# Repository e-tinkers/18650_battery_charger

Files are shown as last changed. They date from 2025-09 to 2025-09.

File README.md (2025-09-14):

## What this about
This repository contains the design files for my 18650 and single cell Li-Po charger which also consists of load-shring circuitry, and a buck/boost converter (3.3V/5.0V, 500mA output) with very low quiescent current (20uA).

18650 battery charger PCB with load sharing and buck/boost converter

## The motivation
All the 18650 battery chargers that can be found from AliExpress have serious design faults, and the 18650 battery is safer to be used with the protection circuit permanently attached to it. With the modification added to 18650, the commercial available battery holders for 18650 no longer fit. So I decided to design my own charger with custom 18650 battery holder to fit the modified battery, and add a low quiescent current buck/boost converter with 3.3V/5V output that I can used for my electronic projects.

add protection circuit permanently to 18650 battery

## The design goals
1. On-board 18650 battery holder able to fit standard 18650 and modified one;
2. USB Type C power input port;
3. Capable to charge either 18650 battery and Li-Po battery (via JST connector);
4. Battery Protection for standard 18650 battery;
5. Load-sharing circuitry so it can power the load while charging;
6. Boost/Buck converter capable to deliver 500mA power with either 3.3V or 5V output;
7. Low quiescent current for IoT application.

Read more in details about the design considerations from my [blog post](https://www.e-tinkers.com/2025/08/design-my-own-tp4056-li-ion-charger-and-iot-power-supply-subsystem/).

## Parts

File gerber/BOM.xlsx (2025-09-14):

Symbol | Value | Description | Qty | LCSC Part No | MOQ | Unit Price | Order Qty | BOM Cost | Order Amount
BT1 | 18650_holder | 18650_holder:18650_holder_PH | 1 | C5290176 | 1 | 0.4061 | 5 | 0.4061 | 2.0305
C4 | 10uF | Capacitor_SMD:C_0603_1608Metric | 1 |  |  | 0.0157 |  | 0.0157
> C1, C2 | 22uF | Capacitor_SMD:C_0603_1608Metric | 2 | C86295 | 50 | 0.0129 | 50 | 0.0258 | 0.0129
> C3, C5, C6 | 0.1uF | Capacitor_SMD:C_0603_1608Metric | 3 |  |  | 0.0022 |  | 0.0066
D1 | BAT60A | Diode_SMD:D_SOD-323 | 1 | C5355496 | 10 | 0.0345 | 20 | 0.0345 | 0.0345
D2 | PWR | LED_SMD:LED_0603_1608Metric | 1 |  |  | 0.015 |  | 0.015
D3 | CHRG | LED_SMD:LED_0603_1608Metric | 1 |  |  | 0.015 |  | 0.015
D4 | STDBY | LED_SMD:LED_0603_1608Metric | 1 |  |  | 0.0178 |  | 0.0178
J1 | Connector_USB_C | XUNPU_TYPEC-304-ACP16:XUNPU_TYPEC-304-ACP16 | 1 |  |  |  |  | 0.01202
J2 | Output | Connector_PinSocket_2.54mm:PinSocket_1x02_P2.54mm_Vertical | 1 |  |  |  |  | 0.0137
J3 | JST PH2 | JST_PH_S2B-PH-SM4-TB_1x02-1MP_P2.00mm_Horizontal | 1 | C7429689 | 10 | 0.0339 | 10 | 0.0288 | 0.339
JP1 | VLED | Jumper:SolderJumper-2_P1.3mm_Bridged_RoundedPad1.0x1.5mm | 1 |  |  |  |  | 0
L1 | 0.47uH | Inductor_SMD:L_Taiyo-Yuden_NR-50xx | 1 | C222905 | 1 | 0.0838 | 10 | 0.0838 | 0.838
Q1 | FDN340P | Package_TO_SOT_SMD:SOT-23_Handsoldering | 1 |  |  |  |  | 0.0463
Q2 | 8205A | 8205A:SOP65P640X120-8N | 1 | C7419210 | 10 | 0.0646 | 10 | 0.0646 | 0.646
R2 | 511k 1% | Resistor_SMD:R_0603_1608Metric | 1 | C861454 | 20 | 0.0366 | 20 | 0.0366 | 0.732
R1 | 309k 1% | Resistor_SMD:R_0603_1608Metric | 1 | C4151043 | 100 | 0.0012 | 100 | 0.0012 | 0.12
R3 | 91k 1% | Resistor_SMD:R_0603_1608Metric | 1 | C137671 | 100 | 0.0067 | 100 | 0.0067 | 0.67
R4 | 100k | Resistor_SMD:R_0603_1608Metric | 1 |  | 100 | 0.001 |  | 0.001
> R6, R7 | 5.1k | Resistor_SMD:R_0603_1608Metric | 2 |  |  | 0.0022 |  | 0.0044
R8 | 100 | Resistor_SMD:R_0603_1608Metric | 1 |  |  | 0.0011 |  | 0.0011
> R5, R9, R10, R12 | 2k | Resistor_SMD:R_0603_1608Metric | 4 | C125933 | 100 | 0.0021 | 100 | 0.0084 | 0.21
R11 | 1k | Resistor_SMD:R_0603_1608Metric | 1 |  |  |  |  | 0.0009
SW1 | PWR | switches:SW_SPDT_MK-12C02 | 1 | C963206 |  |  |  | 0.058
SW2 | SW_DIP_x01 | Button_Switch_SMD:SW_DIP_SPSTx01_Slide_Copal_CHS-01A_W5.08mm_P1.27mm_JPin | 1 | C18198097 | 1 | 0.5728 | 5 | 0.5728 | 2.864
SW3 | BATT | switches:SW_SPDT_MK-12C02 | 1 | C963206 | 10 | 0.058 | 10 | 0.058 | 0.58
U1 | TPS63802 | TPS63802:TPS63802DLAR | 1 | C2845237 | 1 | 0.9466 | 5 | 0.9466 | 4.733
U2 | DW01 | DW01A:SOT23-6 | 1 | C18212691 | 20 | 0.0311 | 20 | 0.0311 | 0.622
U3 | TP4056 | e-tinkers:SOP127P600X175-9N | 1 | C16581 | 5 | 0.1104 | 5 | 0.1677 | 0.552
 |  |  |  |  |  |  |  | 2.68022 | 14.9839

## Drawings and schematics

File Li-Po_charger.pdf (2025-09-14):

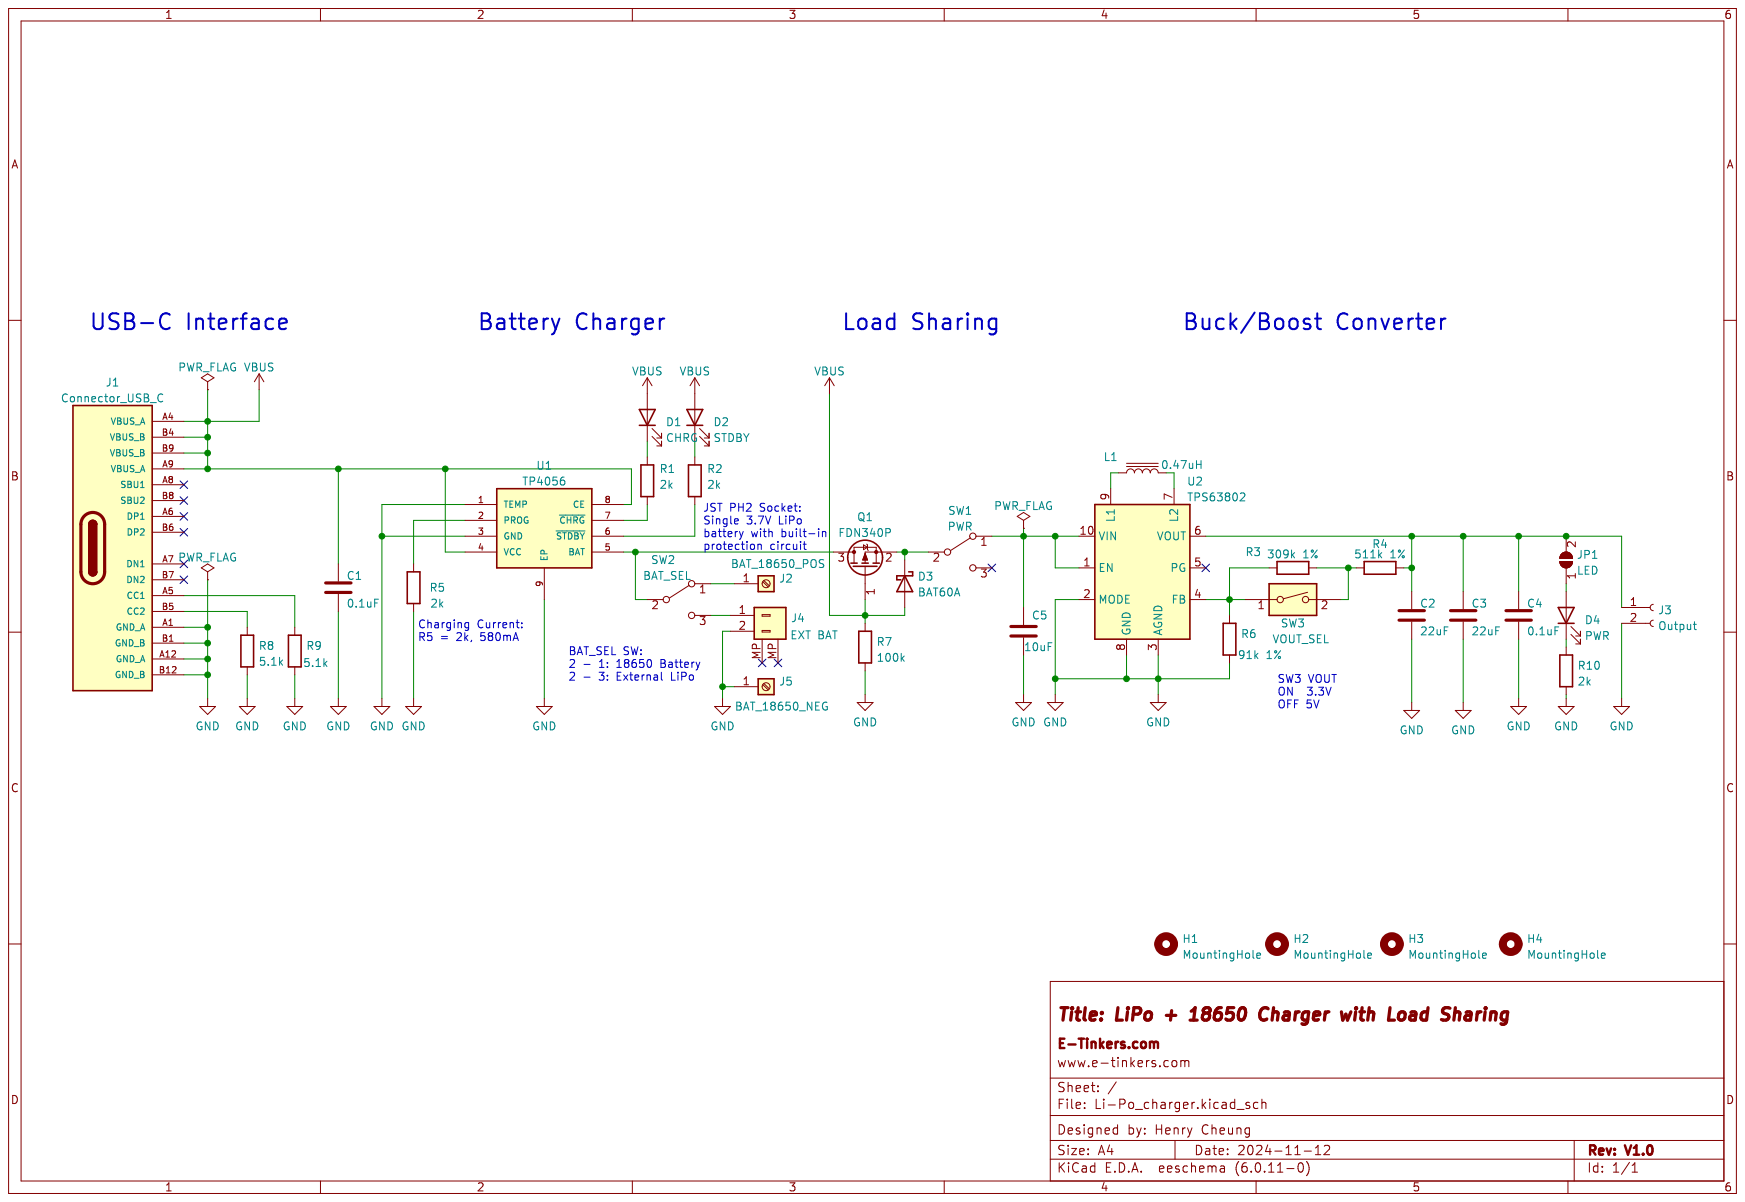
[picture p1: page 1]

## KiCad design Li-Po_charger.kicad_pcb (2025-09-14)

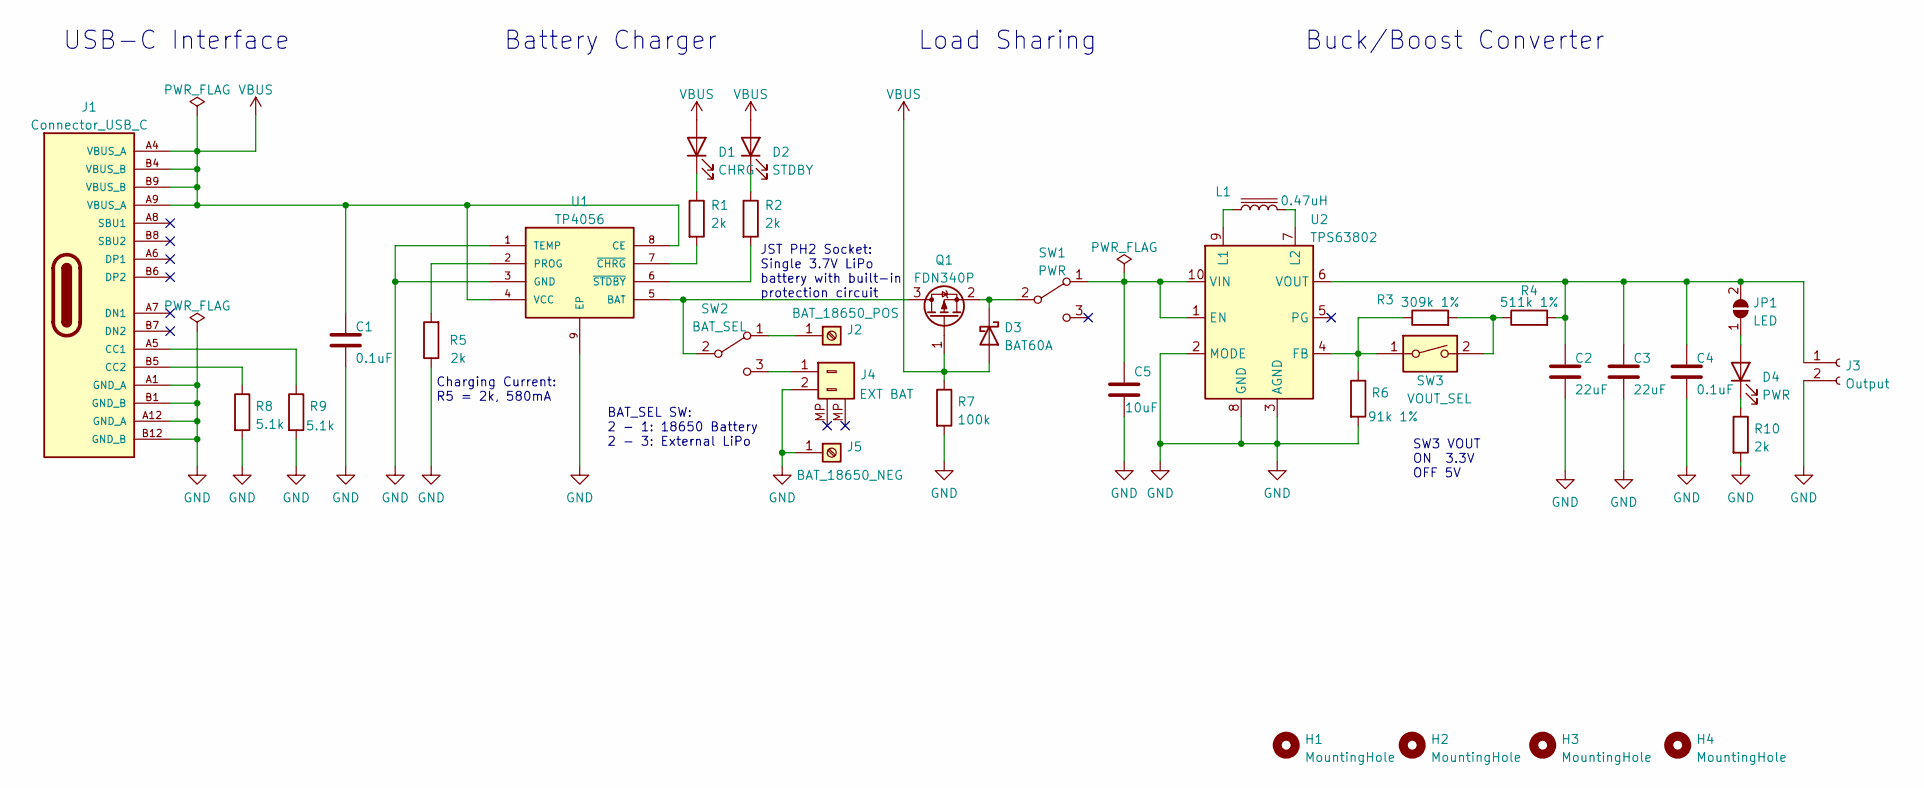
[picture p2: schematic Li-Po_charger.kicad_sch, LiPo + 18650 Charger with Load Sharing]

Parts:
C1, C4: 0.1uF; C_0603_1608Metric
C2, C3: 22uF; C_0603_1608Metric
C5: 10uF; C_0603_1608Metric
D1: CHRG; LED_0603_1608Metric
D2: STDBY; LED_0603_1608Metric
D3: BAT60A; D_SOD-323_HandSoldering
D4: PWR; LED_0603_1608Metric
H1, H2, H3, H4: MountingHole; MountingHole_2.7mm_M2.5
J1: Connector_USB_C; XUNPU_TYPEC-304-ACP16
J2: BAT_18650_POS; BAT-SMD_MY-18650-02
J3: Output; PinSocket_1x02_P2.54mm_Vertical
J4: EXT BAT; JST_PH_S2B-PH-SM4-TB_1x02-1MP_P2.00mm_Horizontal
J5: BAT_18650_NEG; BAT-SMD_MY-18650-02
JP1: LED; SolderJumper-2_P1.3mm_Open_RoundedPad1.0x1.5mm
L1: 0.47uH; L_Taiyo-Yuden_NR-50xx_HandSoldering
Q1: FDN340P; SOT-23_Handsoldering
R1, R2, R5, R10: 2k; R_0603_1608Metric
R3: 309k 1%; R_0603_1608Metric
R4: 511k 1%; R_0603_1608Metric
R6: 91k 1%; R_0603_1608Metric
R7: 100k; R_0603_1608Metric
R8, R9: 5.1k; R_0603_1608Metric
SW1: PWR; SW_SPDT_MK-12C02-C963206
SW2: BAT_SEL; SW_SPDT_MK-12C02-C963206
SW3: VOUT_SEL; SW_DIP_SPSTx01_Slide_Copal_CHS-01A_W5.08mm_P1.27mm_JPin
U1: TP4056; SOP127P600X175-9N
U2: TPS63802; TPS63802DLAR

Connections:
GND: C1.2, C2.2, C3.2, C4.2, C5.2, J1.A1 (GND_A), J1.A12 (GND_A), J1.B1 (GND_B), J1.B12 (GND_B), J3.2, J4.2, J5.1, R5.1, R6.2, R7.2, R8.2, R9.2, R10.2, U1.1 (TEMP), U1.3 (GND), U1.9 (EP), U2.2 (MODE), U2.3 (AGND), U2.8 (GND)
unnamed: C2.1, C3.1, C4.1, J3.1, JP1.2 (B), R4.2, U2.6 (VOUT)
unnamed: C5.1, SW1.1 (A), U2.1 (EN), U2.10 (VIN)
unnamed: D1.1 (K), R1.1
unnamed: D2.1 (K), R2.1
unnamed: D3.1 (K), Q1.2 (S), SW1.2 (B)
unnamed: D4.1 (K), R10.1
unnamed: D4.2 (A), JP1.1 (A)
unnamed: J1.A5 (CC1), R9.1
unnamed: J1.B5 (CC2), R8.1
unnamed: J2.1, SW2.1 (A)
unnamed: J4.1, SW2.3 (C)
unnamed: L1.1, U2.9 (L1)
unnamed: L1.2, U2.7 (L2)
unnamed: Q1.3 (D), SW2.2 (B), U1.5 (BAT)
unnamed: R1.2, U1.7 (~CHRG)
unnamed: R2.2, U1.6 (~STDBY)
unnamed: R3.1, R6.1, SW3.1, U2.4 (FB)
unnamed: R3.2, R4.1, SW3.2
unnamed: R5.2, U1.2 (PROG)
VBUS: C1.1, D1.2 (A), D2.2 (A), D3.2 (A), J1.A4 (VBUS_A), J1.A9 (VBUS_A), J1.B4 (VBUS_B), J1.B9 (VBUS_B), Q1.1 (G), R7.1, U1.4 (VCC), U1.8 (CE)

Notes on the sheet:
Battery Charger
Charging Current: R5 = 2k, 580mA
BAT_SEL SW: 2 - 1: 18650 Battery 2 - 3: External LiPo
Buck/Boost Converter
SW3 VOUT ON 3.3V OFF 5V
USB-C Interface
Load Sharing
JST PH2 Socket: Single 3.7V LiPo battery with built-in protection circuit

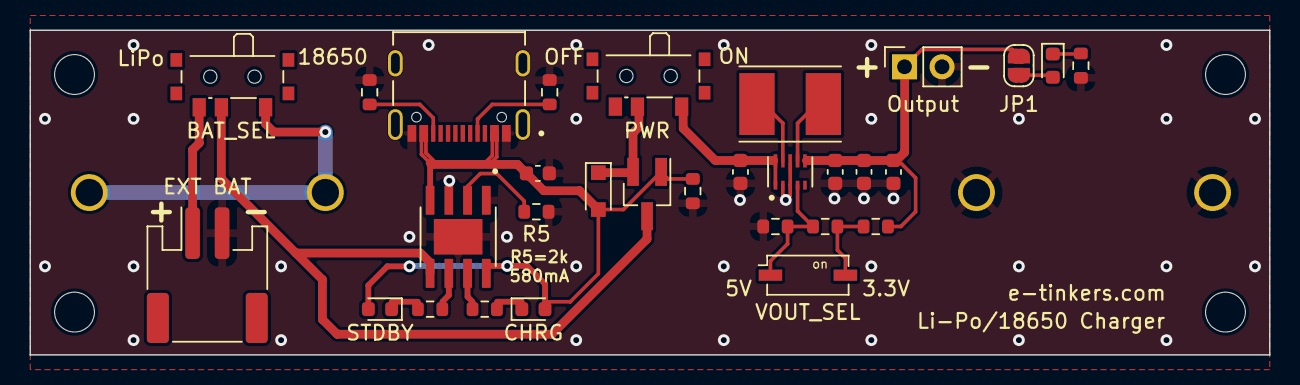
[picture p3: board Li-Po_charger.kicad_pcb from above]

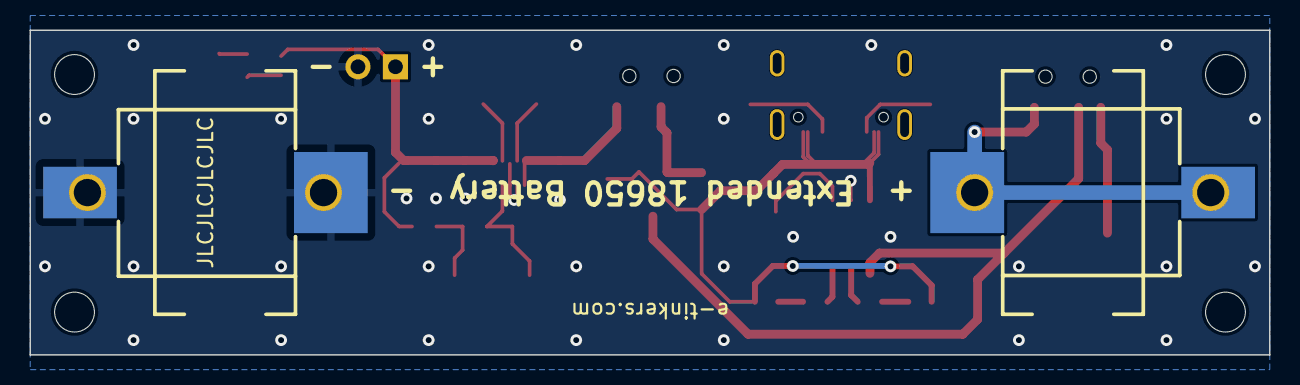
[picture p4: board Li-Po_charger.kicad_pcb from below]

Board: 2 copper layers, 84.0 x 22.0 mm, 36 parts (2 on the bottom side), 21 nets.
